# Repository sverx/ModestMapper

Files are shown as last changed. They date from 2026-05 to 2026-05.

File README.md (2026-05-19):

# the ModestMapper

the ModestMapper is an open _low-cost_ **rewritable** cartridge for the SEGA Master System.

It's based on [doragasu's FrugalMapper cartridge](https://gitlab.com/doragasu/sms-sl2map) and shares many of its features:

- uses a Flash memory chip instead of ROM chips, thus being rewritable
- uses only discrete logic chips, as few of them as possible
- can be programmed and reprogrammed after having being assembled
- supports up to 4 Mbit (512 KiB) but can use 2 Mbit (256 KiB) and 1 Mbit (128 KiB) Flash chips too (currently _untested_ but the design allows for that)

While doragasu's FrugalMapper supports slot-2 SEGA mapper only, the ModestMapper supports both slot-1 **and** slot-2 SEGA mapper, making it perfect for [devkitSMS](https://github.com/sverx/devkitSMS) games that use [transparent code bankswitching](https://github.com/sverx/devkitSMS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) for example, but can be used for any game requiring slot-1 and slot-2 paging (please read the note on the _Words of caution_ section below).

# How it works

the ModestMapper implements only a subset of the complete [SEGA mapper](https://www.smspower.org/Development/Mappers#TheSegaMapper) specifications so:

- slot-0 paging isn't supported, thus the first 16 KiB of the data in the ROM will always be accessible at address $0000-$3FFF
- slot-1 and slot-2 paging **are** supported, thus any of the 16 KiB blocks of the ROM can be accessible at addresses $4000-$7FFF (slot-1) and $8000-$BFFF (slot-2)
- up to 32 × 16-KiB ROM pages are supported
- advanced SEGA mapper features such as bankshifting or write protection aren't supported

# Words of caution

Since address decoding is partial, any writes to addresses $E000-$FFFF (RAM _mirror_ addresses) will work as writes to the SEGA mapper ports $FFFC-$FFFF - see the following table:

       writes to                              |     effect
    ------------------------------------------+----------------------
    %111x xxxx xxxx xx00 ($FFFC and mirrors)  |   _none_ (ignored)
    %111x xxxx xxxx xx01 ($FFFD and mirrors)  |   _none_ (ignored)
    %111x xxxx xxxx xx10 ($FFFE and mirrors)  |   **set slot-1 page**
    %111x xxxx xxxx xx11 ($FFFF and mirrors)  |   **set slot-2 page**

This shouldn't cause any issues provided that the program **never** writes to RAM _mirror_ addresses ([Emulicious](https://emulicious.net)' debugger has a very useful feature to detect if this happens).

Also of note is that the slot-1 and slot-2 pages are **NOT** initialized by the hardware so the [SEGA signature](https://www.smspower.org/Development/ROMHeader) that's **required** by the Master System BIOS to be in the ROM at a certain locations **can't** be located at $7FF0 but **has** to be located at $3FF0 instead (devkitSMS has a macro for that: *SMS_EMBED_SEGA_ROM_HEADER_16KB*) - or at $1FF0.

# How to write a ROM onto the cartridge

You can use either [Raphnet's SMS cartridge reader/programmer](https://www.raphnet-tech.com/products/sms_cartridge_reader_programmer/index.php) with an [updated firmware](https://github.com/sverx/smscprogr) (tested personally) or you can use [doragasu's MegaWiFi programmer](https://gitlab.com/doragasu/mw-prog) (not tested yet but it should work as the ModestMapper is compatible with the FrugalMapper by design).

# License

the ModestMapper cartridge design is Open Hardware, licensed under the CERN-OHL-S license, as it's a  derivate work of [doragasu's FrugalMapper cartridge](https://gitlab.com/doragasu/sms-sl2map)

# Acknowledgements

This project wouldn't have ever been possible without doragasu's FrugalMapper and doragasu's invaluable help while designing this. Also a big THANK YOU to the [SMS Power!](https://www.smspower.org) community and in particolar to @undeveloper ❤️

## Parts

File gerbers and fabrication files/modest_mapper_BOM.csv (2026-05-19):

Id | Designator | Footprint | Quantity | Designation | Supplier and ref
1 | C2,C3,C1,C4,C5 | C_0603_1608Metric | 5 | 100nF
2 | R1,R5,R4,R2,R3 | R_0603_1608Metric | 5 | 4k7
3 | U5,U4 | TSSOP-16_4.4x5mm_P0.65mm | 2 | 74HCT139PW
4 | U1 | TSOP-I-32_11.8x8mm_P0.5mm | 1 | SST39SF040
5 | C6 | C_0805_2012Metric | 1 | 10uF
6 | U2,U3 | TSSOP-20_4.4x6.5mm_P0.65mm | 2 | 74HCT574PW

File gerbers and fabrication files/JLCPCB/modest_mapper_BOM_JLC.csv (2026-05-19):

Comment | Designator | Footprint
100nF | C2,C3,C1,C4,C5 | C_0603_1608Metric
4k7 | R1,R5,R4,R2,R3 | R_0603_1608Metric
74HCT139PW | U5,U4 | TSSOP-16_4.4x5mm_P0.65mm
SST39SF040 | U1 | TSOP-I-32_11.8x8mm_P0.5mm
10uF | C6 | C_0805_2012Metric
74HCT574PW | U2,U3 | TSSOP-20_4.4x6.5mm_P0.65mm

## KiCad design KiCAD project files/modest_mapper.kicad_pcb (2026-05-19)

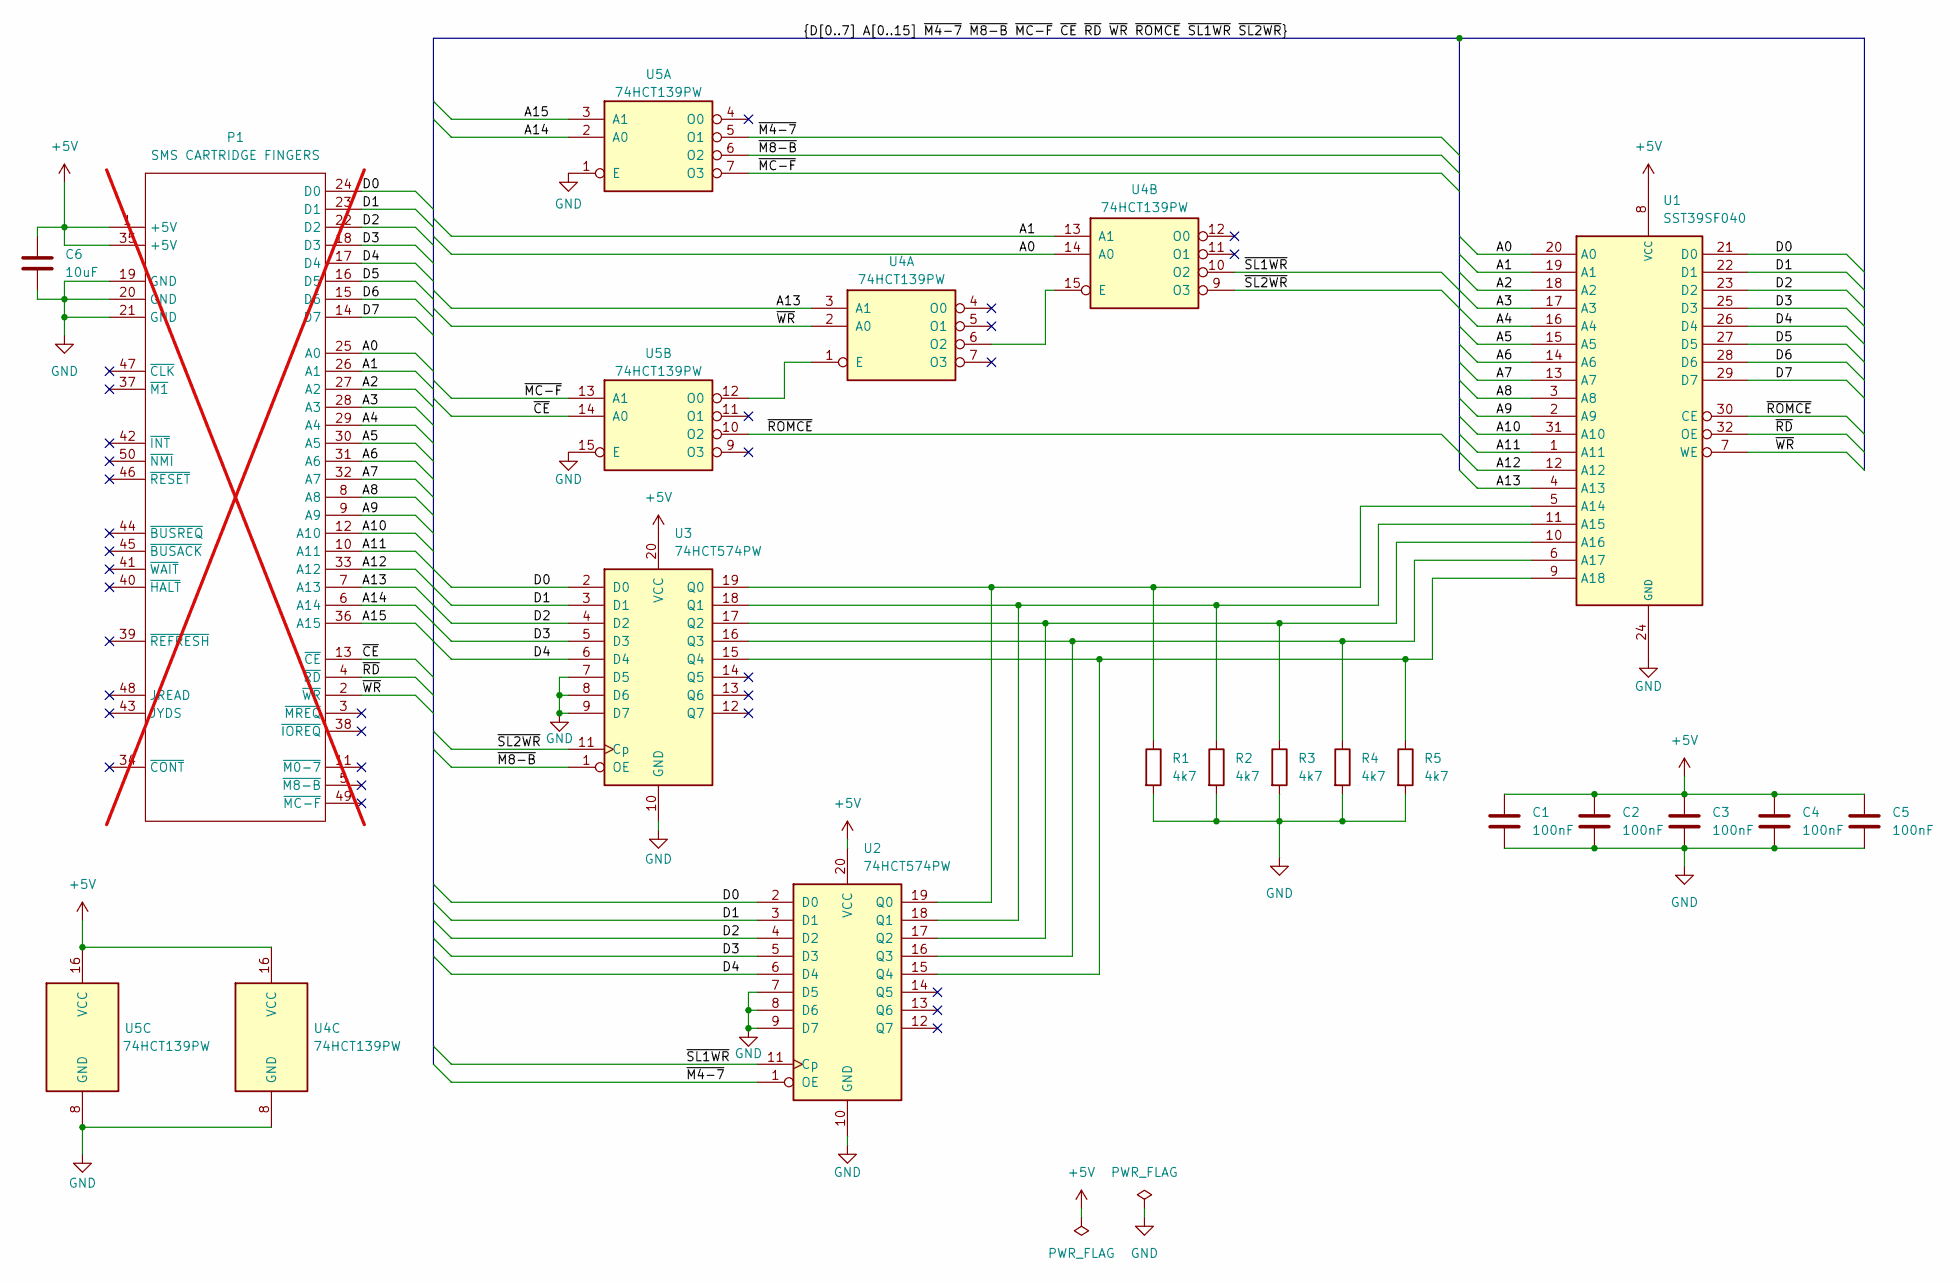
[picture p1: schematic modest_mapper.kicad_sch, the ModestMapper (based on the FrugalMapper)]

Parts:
C1, C2, C3, C4, C5: 100nF; C_0603_1608Metric
C6: 10uF; C_0805_2012Metric
P1: SMS CARTRIDGE FINGERS; not fitted
R1, R2, R3, R4, R5: 4k7; R_0603_1608Metric
U1: SST39SF040; TSOP-I-32_11.8x8mm_P0.5mm
U2, U3: 74HCT574PW; TSSOP-20_4.4x6.5mm_P0.65mm
U4, U5: 74HCT139PW; TSSOP-16_4.4x5mm_P0.65mm

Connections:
+5V: C1.1, C2.1, C3.1, C4.1, C5.1, C6.1, P1.1 (+5V), P1.35 (+5V), U1.8 (VCC), U2.20 (VCC), U3.20 (VCC), U4.16 (VCC), U5.16 (VCC)
/A0: P1.25 (A0), U1.20 (A0), U4.14 (A0)
/A1: P1.26 (A1), U1.19 (A1), U4.13 (A1)
/A2: P1.27 (A2), U1.18 (A2)
/A3: P1.28 (A3), U1.17 (A3)
/A4: P1.29 (A4), U1.16 (A4)
/A5: P1.30 (A5), U1.15 (A5)
/A6: P1.31 (A6), U1.14 (A6)
/A7: P1.32 (A7), U1.13 (A7)
/A8: P1.8 (A8), U1.3 (A8)
/A9: P1.9 (A9), U1.2 (A9)
/A10: P1.12 (A10), U1.31 (A10)
/A11: P1.10 (A11), U1.1 (A11)
/A12: P1.33 (A12), U1.12 (A12)
/A13: P1.7 (A13), U1.4 (A13), U4.3 (A1)
/A14: P1.6 (A14), U5.2 (A0)
/A15: P1.36 (A15), U5.3 (A1)
/D0: P1.24 (D0), U1.21 (D0), U2.2 (D0), U3.2 (D0)
/D1: P1.23 (D1), U1.22 (D1), U2.3 (D1), U3.3 (D1)
/D2: P1.22 (D2), U1.23 (D2), U2.4 (D2), U3.4 (D2)
/D3: P1.18 (D3), U1.25 (D3), U2.5 (D3), U3.5 (D3)
/D4: P1.17 (D4), U1.26 (D4), U2.6 (D4), U3.6 (D4)
/D5: P1.16 (D5), U1.27 (D5)
/D6: P1.15 (D6), U1.28 (D6)
/D7: P1.14 (D7), U1.29 (D7)
/~CE: P1.13 (~CE), U5.14 (A0)
/~M4-7: U2.1 (OE), U5.5 (O1)
/~M8-B: U3.1 (OE), U5.6 (O2)
/~MC-F: U5.7 (O3), U5.13 (A1)
/~RD: P1.4 (~RD), U1.32 (OE)
/~ROMCE: U1.30 (CE), U5.10 (O2)
/~SL1WR: U2.11 (Cp), U4.10 (O2)
/~SL2WR: U3.11 (Cp), U4.9 (O3)
/~WR: P1.2 (~WR), U1.7 (WE), U4.2 (A0)
GND: C1.2, C2.2, C3.2, C4.2, C5.2, C6.2, P1.19 (GND), P1.20 (GND), P1.21 (GND), R1.2, R2.2, R3.2, R4.2, R5.2, U1.24 (GND), U2.7 (D5), U2.8 (D6), U2.9 (D7), U2.10 (GND), U3.7 (D5), U3.8 (D6), U3.9 (D7), U3.10 (GND), U4.8 (GND), U5.1 (E), U5.8 (GND), U5.15 (E)
unnamed: R1.1, U1.5 (A14), U2.19 (Q0), U3.19 (Q0)
unnamed: R2.1, U1.11 (A15), U2.18 (Q1), U3.18 (Q1)
unnamed: R3.1, U1.10 (A16), U2.17 (Q2), U3.17 (Q2)
unnamed: R4.1, U1.6 (A17), U2.16 (Q3), U3.16 (Q3)
unnamed: R5.1, U1.9 (A18), U2.15 (Q4), U3.15 (Q4)
unnamed: U4.1 (E), U5.12 (O0)
unnamed: U4.6 (O2), U4.15 (E)

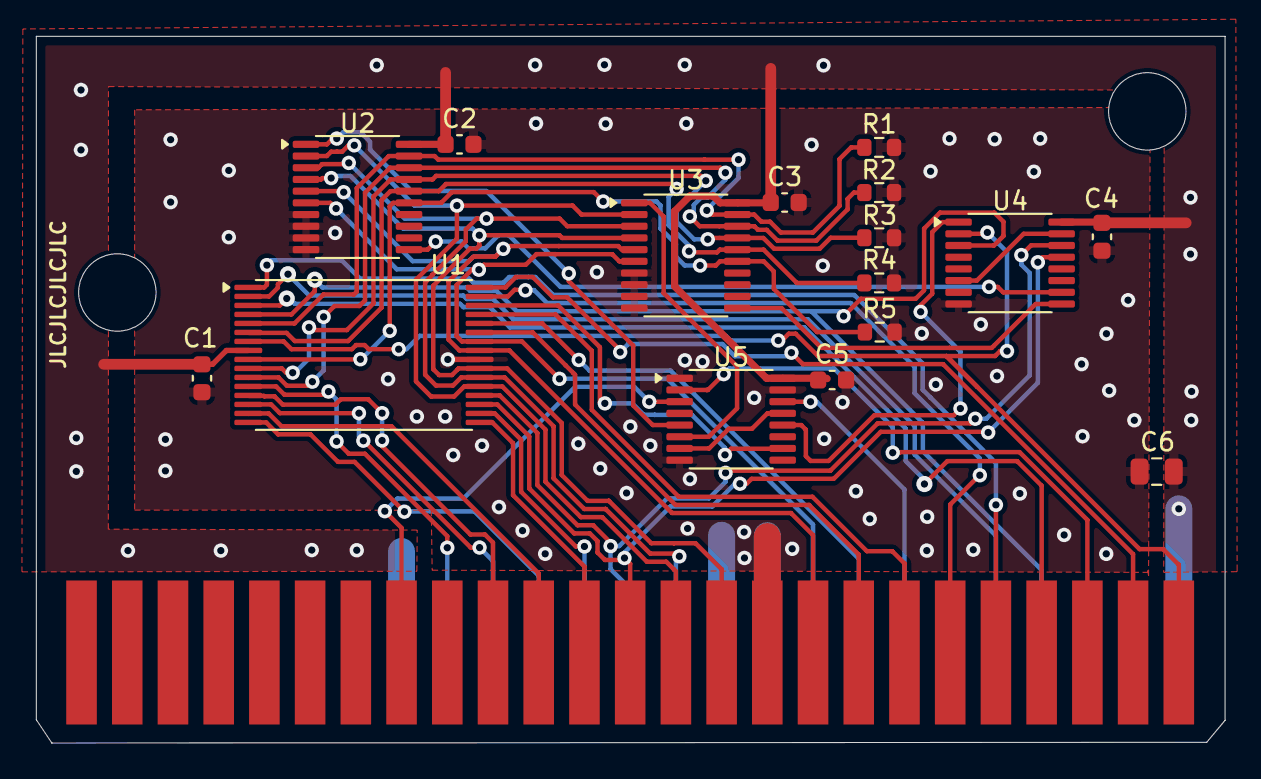
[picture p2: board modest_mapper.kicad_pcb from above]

Board: 4 copper layers, 66.0 x 39.3 mm, 17 parts (0 on the bottom side), 42 nets.
